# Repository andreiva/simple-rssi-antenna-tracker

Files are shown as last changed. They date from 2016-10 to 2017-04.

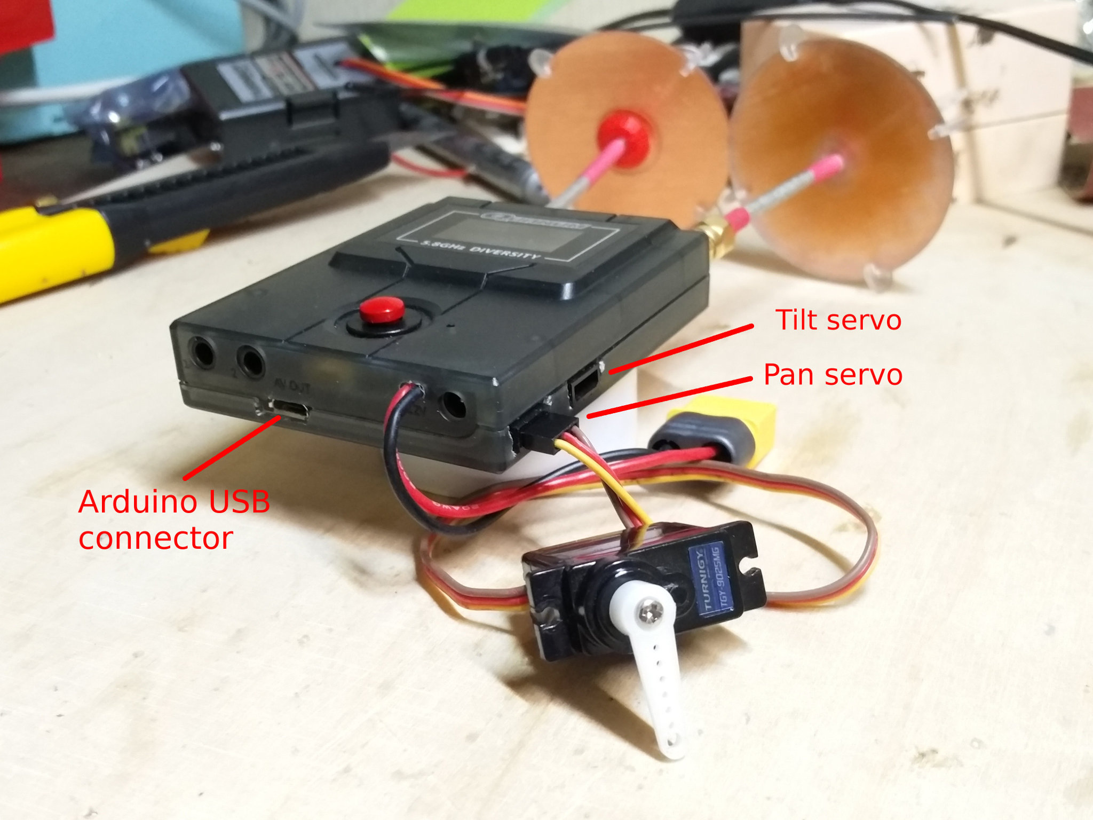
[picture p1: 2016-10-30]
images/assembled.jpg

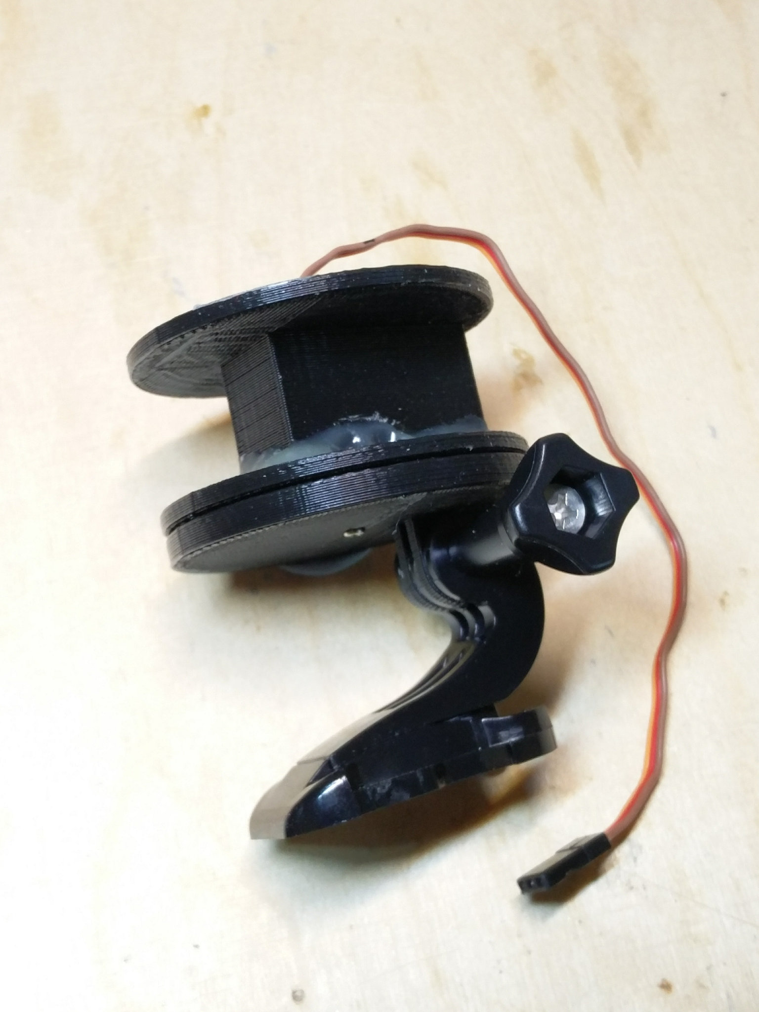
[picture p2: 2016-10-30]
images/servo-mount-2.jpg

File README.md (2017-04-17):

Simple RSSI Antenna Tracker
===========================

This tracker uses [Quanum RC540R 5.8GHz 40CH Race Band FPV Diversity Receiver](https://www.hobbyking.com/en_us/5-8ghz-32ch-8-race-channels-diversity-vrx.html)
which has two video receivers with RSSI output. RSSI is measured with an Arduino's analog inputs, signal strength is compared and tracker head is turned towards stronger signal with servo.

This tracker relies solely on RSSI, no GPS or compass is involved.
This means you can track any 5.8GHz signal source to which the receiver is tuned to.
No pairing, no telemetry, no configuration, just tune and track.

### Pros:
* It's cheap and simple. You probably already have most of the the parts.
* no GPS needed
* no telemetry needed
* can track any 5.8GHz source

### Cons:
* tracking is relative
* tracker doesn't really know where the target is
* may wander off target
* tracks only in horizontal axis

# What will you need
* [Quanum RC540R 5.8GHz 40CH Race Band FPV Diversity Receiver](https://www.hobbyking.com/en_us/5-8ghz-32ch-8-race-channels-diversity-vrx.html)
    * known to work with: FR632, Boscam D58-2
* Two directional 5.8GHz antennas, helical or patch
* [Arduino Pro Mini ATmega32U4](http://www.ebay.com/sch/i.html?_from=R40&_sacat=0&_nkw=Arduino++atmega+32u4&rt=nc&LH_BIN=1) $4
* One servo, 9 gramms or similar 4$
* [5V voltage regulator](http://www.ebay.com/sch/i.html?_from=R40&_trksid=p2047675.m570.l1313.TR0.TRC0.H0.TRS0&_nkw=MP1584EN&_sacat=0)
* tracker head mount, 3D printed or made from scrap

### Youtube video
[https://www.youtube.com/watch?v=aACTKziuDVE](https://www.youtube.com/watch?v=aACTKziuDVE)

### Timer.h Arduino library
To install Timer library, download the ZIP file here:
[https://github.com/JChristensen/Timer](https://github.com/JChristensen/Timer)

How to install libraries
[https://www.youtube.com/watch?v=Alz-rX6lkEw](https://www.youtube.com/watch?v=Alz-rX6lkEw)

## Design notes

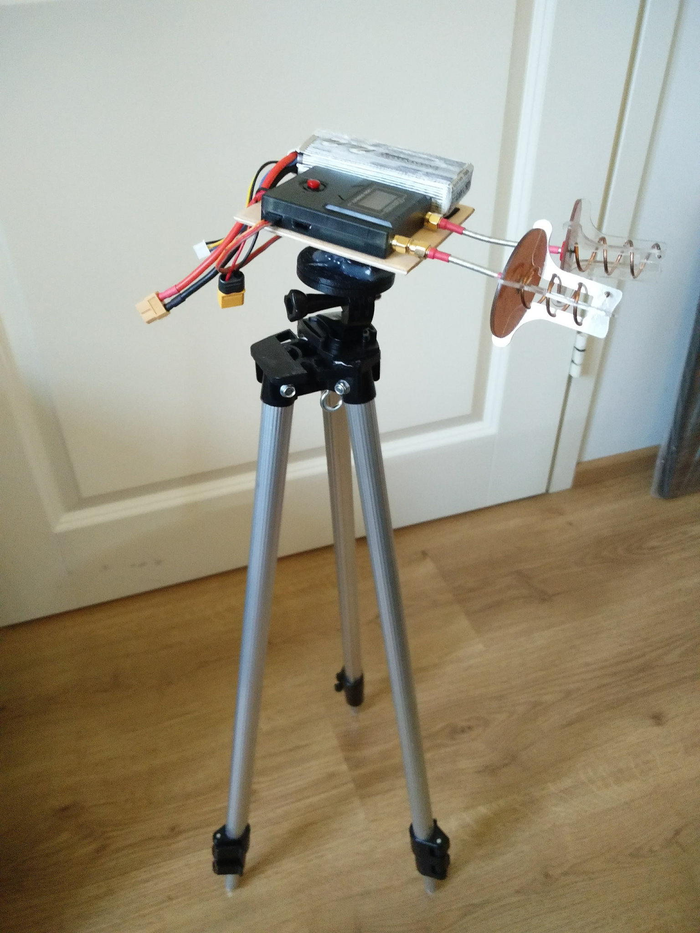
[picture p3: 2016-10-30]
images/tripod.jpg

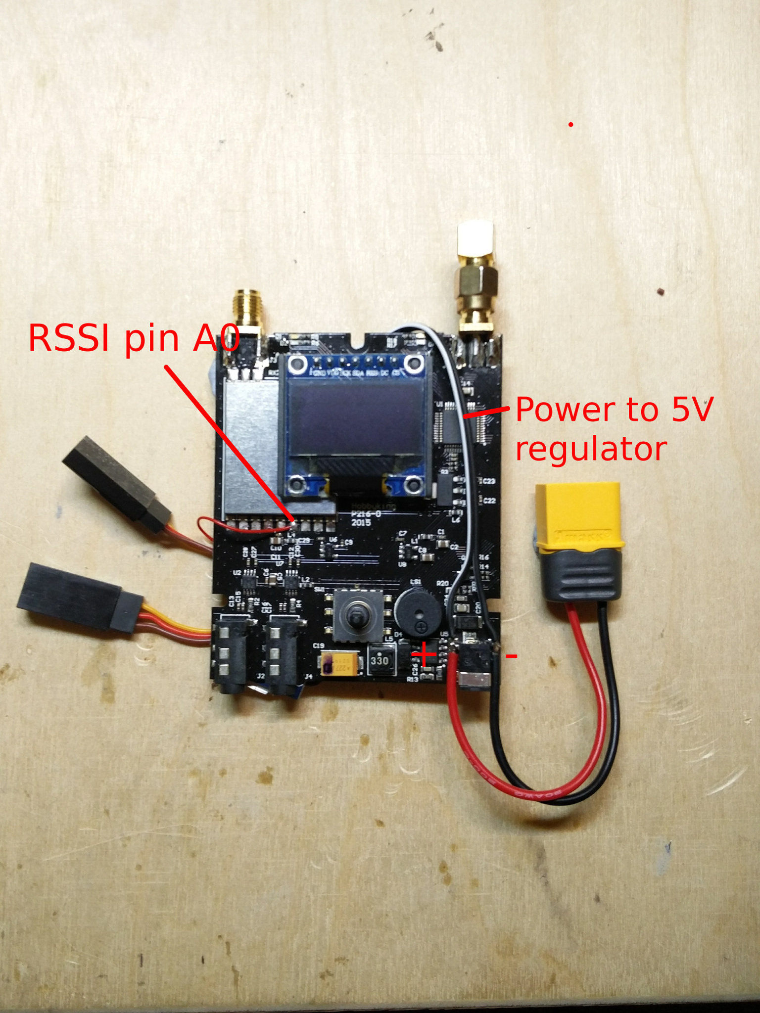
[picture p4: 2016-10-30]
images/top.jpg

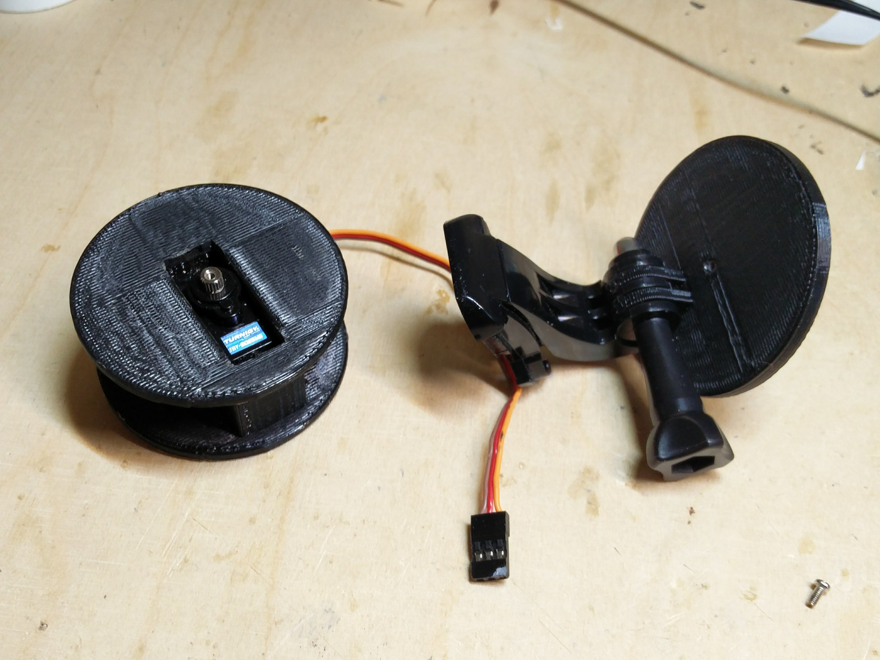
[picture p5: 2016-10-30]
images/servo-mount-1.jpg

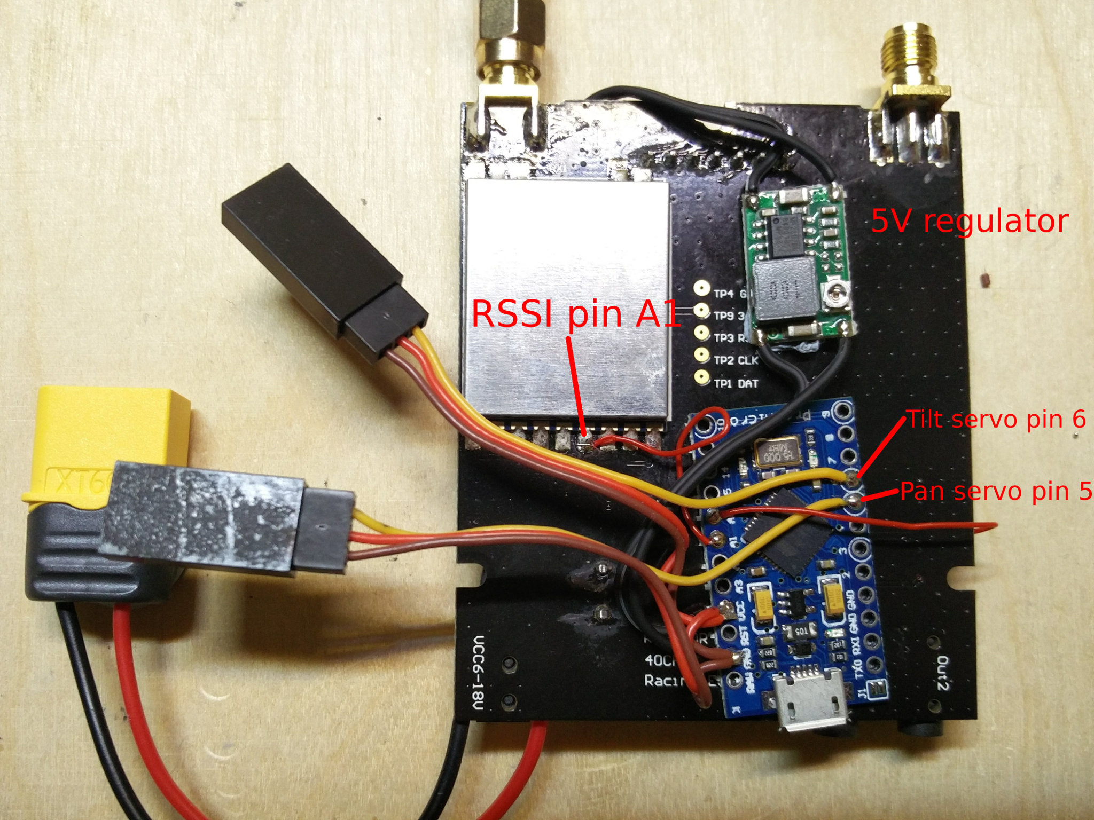
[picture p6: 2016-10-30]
images/bottom.jpg

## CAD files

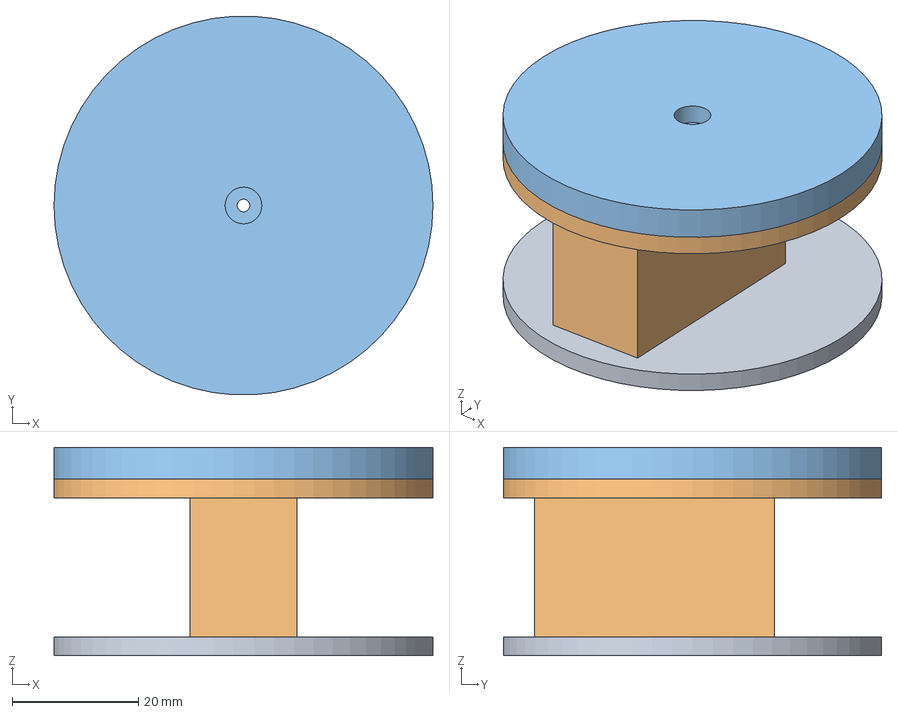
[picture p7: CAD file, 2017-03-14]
servo-mount-3d/tracke-servo-rig.fcstd
60.0 x 59.9 x 33.0 mm

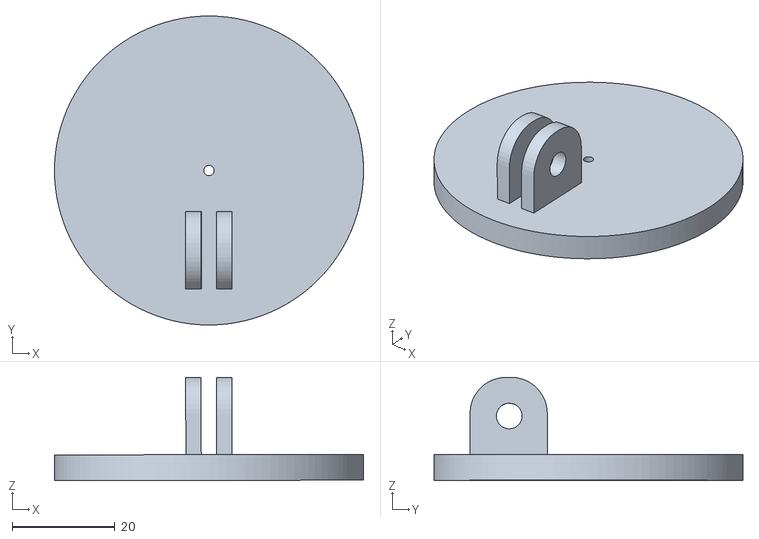
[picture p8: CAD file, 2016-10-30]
servo-mount-3d/bottom-gopro.stl
60.0 x 60.0 x 20.1

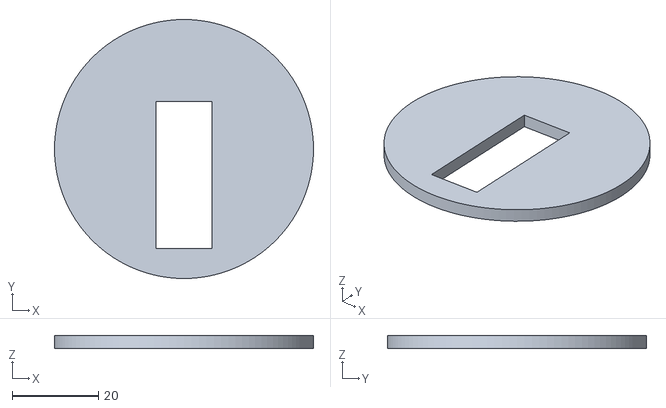
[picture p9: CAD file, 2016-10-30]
servo-mount-3d/servo-body-bottom.stl
60.0 x 60.0 x 3.00

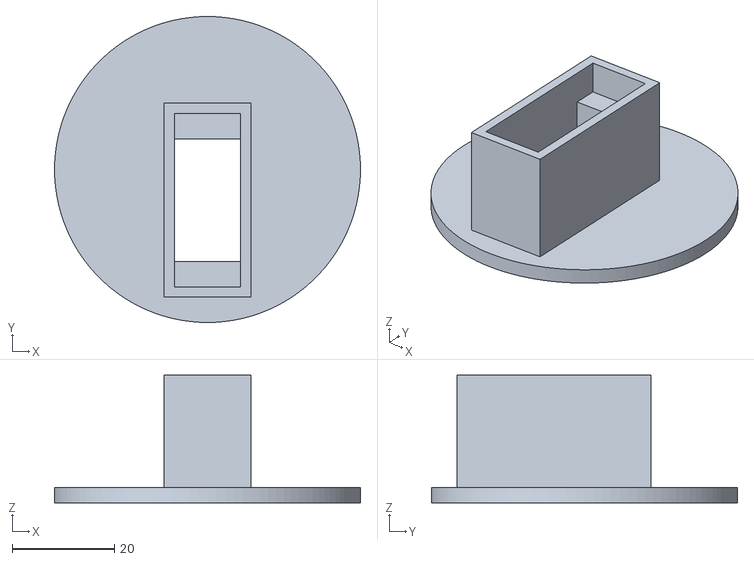
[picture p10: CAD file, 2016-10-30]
servo-mount-3d/servo-body.stl
60.0 x 60.0 x 25.0

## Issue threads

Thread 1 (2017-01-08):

error: 'Timer' does not name a type

MoistNugget666, 2017-01-08:
`simple-rssi-antenna-tracker.ino:101: error: 'Timer' does not name a type
simple-rssi-antenna-tracker.ino: In function 'void setup()':
simple-rssi-antenna-tracker.ino:122: error: 'timer' was not declared in this scope
simple-rssi-antenna-tracker.ino: In function 'void loop()':
simple-rssi-antenna-tracker.ino:129: error: 'timer' was not declared in this scope
`
hello,
im fairly new to adruino programming and get this when i try to compile. any idea how to fix it?

andreiva, 2017-01-09:
Hi,
the problem is missing Timer.h library, you need to install it manually.
Download ZIP file from here https://github.com/JChristensen/Timer  then
extract zip content in (assuming youre using windows) My
Documents\Arduino\libraries\

There are several ways to install libraries, check out this video:
https://www.youtube.com/watch?v=K1cIWCBKaUY

-Andrei

On Sun, Jan 8, 2017 at 4:47 PM, MoistNugget666 <notifications@github.com>
wrote:

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

yoowicked, 2018-12-06:
Need help here! I am using arduino1.0.5 and have installed the timer library but still having the same error message. Any advice to sort it out?

yoowicked, 2018-12-06:
By the way, the video link in your comment is no longer available. Do you have another link? Thanks!

andreiva, 2018-12-11:
Hi, just search YouTube "how to install libraries in adruino" or something
similar. There should plenty of results.

On Dec 6, 2018 08:59, "yoowicked" <notifications@github.com> wrote:

By the way, the video link in your comment is no longer available. Do you
have another link? Thanks!

—
You are receiving this because you commented.

Reply to this email directly, view it on GitHub
<https://github.com/andreiva/simple-rssi-antenna-tracker/issues/1#issuecomment-444768768>,
or mute the thread
<https://github.com/notifications/unsubscribe-auth/ABtNEHdngVj-orlfRdJBvW0o8JX9w2buks5u2MA0gaJpZM4LdtNV>
.

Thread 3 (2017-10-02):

Cant compile

FranzAr, 2017-10-02:
Tried to compile the sketch, but won't work. Any idea what may be the problem

Greets, Franz

```
Arduino: 1.8.5 (Windows 8.1), Board: "Arduino Nano, ATmega328P"

Build-Optionen wurden verändert, alles wird neu kompiliert
D:\arduino\tracker\simple-rssi-antenna-tracker\simple-rssi-antenna-tracker.ino: In function 'void setup()':

simple-rssi-antenna-tracker:122: error: no matching function for call to 'Timer::every(int, void (&)())'

   timer.every(50, mainLoop);

                           ^

D:\arduino\tracker\simple-rssi-antenna-tracker\simple-rssi-antenna-tracker.ino:122:27: note: candidates are:

In file included from D:\arduino\tracker\simple-rssi-antenna-tracker\simple-rssi-antenna-tracker.ino:10:0:

C:\Users\Franz\Documents\Arduino\libraries\Timer-2.1/Timer.h:40:10: note: int8_t Timer::every(long unsigned int, void (*)(void*), void*)

   int8_t every(unsigned long period, void (*callback)(void*), void* context);

          ^

C:\Users\Franz\Documents\Arduino\libraries\Timer-2.1/Timer.h:40:10: note:   candidate expects 3 arguments, 2 provided

C:\Users\Franz\Documents\Arduino\libraries\Timer-2.1/Timer.h:41:10: note: int8_t Timer::every(long unsigned int, void (*)(void*), int, void*)

   int8_t every(unsigned long period, void (*callback)(void*), int repeatCount, void* context);

          ^

C:\Users\Franz\Documents\Arduino\libraries\Timer-2.1/Timer.h:41:10: note:   candidate expects 4 arguments, 2 provided

simple-rssi-antenna-tracker:123: error: no matching function for call to 'Timer::every(int, void (&)())'

   timer.every(5, measureRSSI);

                             ^

D:\arduino\tracker\simple-rssi-antenna-tracker\simple-rssi-antenna-tracker.ino:123:29: note: candidates are:

In file included from D:\arduino\tracker\simple-rssi-antenna-tracker\simple-rssi-antenna-tracker.ino:10:0:

C:\Users\Franz\Documents\Arduino\libraries\Timer-2.1/Timer.h:40:10: note: int8_t Timer::every(long unsigned int, void (*)(void*), void*)

   int8_t every(unsigned long period, void (*callback)(void*), void* context);

          ^

C:\Users\Franz\Documents\Arduino\libraries\Timer-2.1/Timer.h:40:10: note:   candidate expects 3 arguments, 2 provided

C:\Users\Franz\Documents\Arduino\libraries\Timer-2.1/Timer.h:41:10: note: int8_t Timer::every(long unsigned int, void (*)(void*), int, void*)

   int8_t every(unsigned long period, void (*callback)(void*), int repeatCount, void* context);

          ^

C:\Users\Franz\Documents\Arduino\libraries\Timer-2.1/Timer.h:41:10: note:   candidate expects 4 arguments, 2 provided

exit status 1
no matching function for call to 'Timer::every(int, void (&)())'

```

andreiva, 2017-10-03:
Looks like you haven't installed Timer library. Take a look at README, there you'll find instructions how to do it.

FranzAr, 2017-10-03:
I'm sorry but timer is installed. Tried it on 2 different machines and several Arduino versions. Can't compile it, alway the same errors. Maybe I'm to stupid, sorry

FranzAr, 2017-10-03:
Found it, 2.x timer lib is not working, had to take old 1.3 branch. Now it works. Maybe you should mention this somewhere ;-) Thank you

andreiva, 2017-10-03:
Okay thanks, I'll check it out later.

Closed 2017-10-03.

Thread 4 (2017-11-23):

code issue

vannoz, 2017-11-23:
hello Andrei, I got an error when trying to compile this code...
[code]
`//#include <LiquidCrystal.h>

/*
  Simple RSSI Antenna Tracker
  RELATIVE
*/

#include <Servo.h>
#include <Timer.h>

/*
    For testing different curves
    All new curves are more precise
    and maintain lock better than old RELATIVE

    Uncomment one
*/
//#define EXPONENTIAL       // OK
//#define RELATIVE          // old, don't use
#define SIGMOID             // Best
//#define PROPORTIONAL      // twitchy

#define SIGMOID_SLOPE       1
#define SIGMOID_OFFSET      4

#if !defined(EXPONENTIAL) ^ !defined(SIGMOID) ^ !defined(PROPORTIONAL) ^ !defined(RELATIVE)
// all good
#else
#error "Please define ONE tracking curve: EXPONENTIAL, SIGMOID, PROPORTIONAL, RELATIVE"
#endif

/*
   Pin mapping
   You can change these pins, just make sure that
   RSSI pins are analog inputs
   and servo pin supports PWM
*/
#define LEFT_RSSI_PIN       A0     // analog RSSI measurement pin
#define RIGHT_RSSI_PIN     A1
#define PAN_SERVO_PIN    13     // Pan servo pin

/*
   There is going to be some difference in receivers,
   one is going to be less sensitive than the other.
   It will result in slight offset when tracker is centered on target

   Find value that evens out RSSI
*/
#define RSSI_OFFSET_RIGHT   0
#define RSSI_OFFSET_LEFT    0

/*
   MIN and MAX RSSI values corresponding to 0% and 100% from receiver
   See serial monitor
*/
#define RSSI_MAX            400
#define RSSI_MIN            120

/*
   Safety limits for servo

   Find values where servo doesn't buzz at full deflection
*/
#define SERVO_MAX           180
#define SERVO_MIN           0

/*
   Servo 'speed' limits
   MAX and MIN step in degrees
*/
#define SERVO_MAX_STEP      5
#define SERVO_MIN_STEP      0.09     // prevents windup and servo crawl

/*
   Center deadband value!
   Prevents tracker from oscillating when target is in the center
   When using SIGMOID or EXPONENTIAL you can set this almost to 0
*/
#define DEADBAND            5
//int DEADBAND = analogRead(A2)/200; // tolleranza tra dx e sx entro cui non muovere il servo
/*
   Depending which way around you put your servo
   you may have to change direction

   either 1 or -1
*/
#define SERVO_DIRECTION     1

#define FIR_SIZE            10
#define LAST                FIR_SIZE - 1

uint16_t rssi_left_array[FIR_SIZE];
uint16_t rssi_right_array[FIR_SIZE];

float anglePan = 90;
boolean debug = false;
//LiquidCrystal lcd(12,11,5,4,3,2);

Timer timer;
Servo servoPan;
//----------------------------------------------------------------------------------//

void setup() {
  servoPan.attach(PAN_SERVO_PIN);
  servoPan.write(90);

  // lcd.begin(16,2);
  // lcd.setCursor(0,0);
  // lcd.print("pos");
  // lcd.setCursor(7,0); // pos....deg.......
  // lcd.print("deg");   // rssisx....rssidx...
  // lcd.setCursor(0,1); //
  // lcd.print("rssisx");
  // lcd.setCursor(10,1);
  // lcd.print("rssidx");

  // wipe array
  for (int i = 0; i < FIR_SIZE; i++) {
    rssi_right_array[i] = 0;
    rssi_left_array[i] = 0;
  }

  Serial.begin(115200);
  while (!debug) {
    delay(3000);
    debug = true;
  }

  timer.every(50, mainLoop);
  timer.every(5, measureRSSI);

}
//---------------------------------------------------------------------------------//
void loop() {

  timer.update();

}

//-------------------------------------------------------------------------------------------------//
void mainLoop() {

  uint16_t avgLeft = max(avg(rssi_left_array, FIR_SIZE) + RSSI_OFFSET_LEFT, RSSI_MIN);
  uint16_t avgRight = max(avg(rssi_right_array, FIR_SIZE) + RSSI_OFFSET_RIGHT, RSSI_MIN);

  //  If avg RSSI is above 90%, don't move
  //  if ((avgRight + avgLeft) / 2 > 360) {
  //    return;
  //  }

  /*
     the lower total RSSI is, the lower deadband gets
     allows more precise tracking when target is far away
  */
  uint8_t dynamicDeadband = (float(avgRight + avgLeft) / 2 - RSSI_MIN) / (RSSI_MAX - RSSI_MIN) * DEADBAND;

  // if target is in the middle, don't move
  if (abs(avgRight - avgLeft) < dynamicDeadband ) {
    return;
  }

  float ang = 0;

  // move towards stronger signal
  if (avgRight > avgLeft) {

#if defined(EXPONENTIAL)
    float x = float(avgRight - avgLeft);
    x = x * x / 500;
    ang = x * SERVO_DIRECTION * -1;
#endif

#if defined(RELATIVE)
    ang = float(avgRight / avgLeft) * (SERVO_DIRECTION * -1);
#endif

#if defined(SIGMOID)
    float x = float(avgRight - avgLeft) / 10;
    x = SERVO_MAX_STEP / (1 + exp(-SIGMOID_SLOPE * x + SIGMOID_OFFSET));
    ang = x * SERVO_DIRECTION * -1;
#endif

#if defined(PROPORTIONAL)
    float x = float(avgRight - avgLeft) / 10;
    ang = x * SERVO_DIRECTION * -1;
#endif
  }
  else {

#if defined(EXPONENTIAL)
    float x = float(avgLeft - avgRight);
    x = x * x / 500;
    ang = x * SERVO_DIRECTION;
#endif

#if defined(RELATIVE)
    ang = float(avgLeft / avgRight) * SERVO_DIRECTION;
#endif

#if defined(SIGMOID)
    float x = float(avgLeft - avgRight) / 10;
    x = SERVO_MAX_STEP / (1 + exp(-SIGMOID_SLOPE * x + SIGMOID_OFFSET));
    ang = x * SERVO_DIRECTION;
#endif

#if defined(PROPORTIONAL)
    float x = float(avgLeft - avgRight) / 10;
    ang = x * SERVO_DIRECTION;
#endif
  }

  // upper and lower limit for angle step
  ang = (abs(ang) > SERVO_MAX_STEP ? SERVO_MAX_STEP * ang / abs(ang) : ang);
  ang = (abs(ang) < SERVO_MIN_STEP ? 0 : ang);

  // move servo by n degrees
  movePanBy(ang);

  if (debug) {
    //    Serial.print("RSSI%: ");
    //    Serial.print(map(avgLeft, RSSI_MIN, RSSI_MAX, 0, 100));
    //    Serial.print(", ");
    //    Serial.print(map(avgRight, RSSI_MIN, RSSI_MAX, 0, 100));

    // raw rssi values, use these for RSSI_MIN and RSSI_MAX
    Serial.print("Calibration - left: ");
    Serial.print(avgLeft);
    Serial.print(" right: ");
    Serial.print(avgRight);

    Serial.print(" servo-angle: ");
    Serial.println(anglePan);
  }
}

void movePanBy(float angle) {

  anglePan += angle;
  anglePan = limit(SERVO_MIN, SERVO_MAX, anglePan);
  servoPan.write(anglePan);
}

void measureRSSI() {

  advanceArray(rssi_left_array, FIR_SIZE);
  advanceArray(rssi_right_array, FIR_SIZE);

  rssi_left_array[LAST] = analogRead(LEFT_RSSI_PIN);
  rssi_right_array[LAST] = analogRead(RIGHT_RSSI_PIN);
}

uint16_t avg(uint16_t samples[], uint8_t n) {

  uint32_t summ = 0;
  for (uint8_t i = 0; i < n; i++) {
    summ += samples[i];
  }

  return uint16_t(summ / n);
}

void advanceArray(uint16_t *samples, uint8_t n) {

  for (uint8_t i = 0; i < n - 1; i++) {
    samples[i] = samples[i + 1];
  }
}

float limit(float lowerLimit, float upperLimit, float var) {

  return min(max(var, lowerLimit), upperLimit);
}
//lcd.setCursor(4, 0);
//lcd.print(anglePan);
//lcd.setCursor(8, 1);
//lcd.print(LEFT_RSSI_PIN);
//lcd.setCursor(13, 1);
//lcd.print(RIGHT_RSSI_PIN);
`

*******************************************************************************
**1. the error i got is here follwing. the timer library is installed correctly..:**

libraries\Timer\Event.cpp.o (symbol from plugin): In function `Event::Event()':

(.text+0x0): multiple definition of `Event::Event()'

sketch\Event.cpp.o (symbol from plugin):(.text+0x0): first defined here

libraries\Timer\Event.cpp.o (symbol from plugin): In function `Event::Event()':

(.text+0x0): multiple definition of `Event::Event()'

sketch\Event.cpp.o (symbol from plugin):(.text+0x0): first defined here

libraries\Timer\Event.cpp.o (symbol from plugin): In function `Event::Event()':

(.text+0x0): multiple definition of `Event::update(unsigned long)'

sketch\Event.cpp.o (symbol from plugin):(.text+0x0): first defined here

libraries\Timer\Event.cpp.o (symbol from plugin): In function `Event::Event()':

(.text+0x0): multiple definition of `Event::update()'

sketch\Event.cpp.o (symbol from plugin):(.text+0x0): first defined here

libraries\Timer\Timer.cpp.o (symbol from plugin): In function `Timer::Timer()':

(.text+0x0): multiple definition of `Timer::Timer()'

sketch\Timer.cpp.o (symbol from plugin):(.text+0x0): first defined here

libraries\Timer\Timer.cpp.o (symbol from plugin): In function `Timer::Timer()':

(.text+0x0): multiple definition of `Timer::Timer()'

sketch\Timer.cpp.o (symbol from plugin):(.text+0x0): first defined here

libraries\Timer\Timer.cpp.o (symbol from plugin): In function `Timer::Timer()':

(.text+0x0): multiple definition of `Timer::stop(signed char)'

sketch\Timer.cpp.o (symbol from plugin):(.text+0x0): first defined here

libraries\Timer\Timer.cpp.o (symbol from plugin): In function `Timer::Timer()':

(.text+0x0): multiple definition of `Timer::update(unsigned long)'

sketch\Timer.cpp.o (symbol from plugin):(.text+0x0): first defined here

libraries\Timer\Timer.cpp.o (symbol from plugin): In function `Timer::Timer()':

(.text+0x0): multiple definition of `Timer::update()'

sketch\Timer.cpp.o (symbol from plugin):(.text+0x0): first defined here

libraries\Timer\Timer.cpp.o (symbol from plugin): In function `Timer::Timer()':

(.text+0x0): multiple definition of `Timer::findFreeEventIndex()'

sketch\Timer.cpp.o (symbol from plugin):(.text+0x0): first defined here

libraries\Timer\Timer.cpp.o (symbol from plugin): In function `Timer::Timer()':

(.text+0x0): multiple definition of `Timer::every(unsigned long, void (*)(), int)'

sketch\Timer.cpp.o (symbol from plugin):(.text+0x0): first defined here

libraries\Timer\Timer.cpp.o (symbol from plugin): In function `Timer::Timer()':

(.text+0x0): multiple definition of `Timer::every(unsigned long, void (*)())'

sketch\Timer.cpp.o (symbol from plugin):(.text+0x0): first defined here

libraries\Timer\Timer.cpp.o (symbol from plugin): In function `Timer::Timer()':

(.text+0x0): multiple definition of `Timer::after(unsigned long, void (*)())'

sketch\Timer.cpp.o (symbol from plugin):(.text+0x0): first defined here

libraries\Timer\Timer.cpp.o (symbol from plugin): In function `Timer::Timer()':

(.text+0x0): multiple definition of `Timer::oscillate(unsigned char, unsigned long, unsigned char, int)'
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
andreiva, 2017-11-28:
Were you able to solve the problem?

vannoz, 2017-11-28:
Hello...i tried to merge two .ino code, one is your code and one the
diversity rx5808 ino code....but they are using a same name library...the
timer.h
So there are some problem...can You send me your mail? I'll send you what i
did for your help...
Thanks

Il 28/nov/2017 12:58, "andreiva" <notifications@github.com> ha scritto:

Were you able to solve the problem?

—
You are receiving this because you authored the thread.
Reply to this email directly, view it on GitHub
<https://github.com/andreiva/simple-rssi-antenna-tracker/issues/4#issuecomment-347501543>,
or mute the thread
<https://github.com/notifications/unsubscribe-auth/AbS__sbHPh499y2M1WsJwNuCqUj5xLR0ks5s6_VogaJpZM4QoqqV>
.

vannoz, 2017-11-28:
you program doesn't allow to choose the video channel, so I found this code
which is a diversity based on the RX5808:
https://github.com/sheaivey/rx5808-pro-diversity

so I tried to put them together but I find a conflict on two libraries that
have the same name (timer.h) .... and i do not have the skills to make it
one

in the attached file, I tried to make the merge ... I also entered the
commands for the TILT servo .... but putting it on arduino, the servo
trembles ... it goes back and forth as crazy..

 hardware part:
in practice the antenna will consist of 4 helical antennas: Right and Left
to control the PAN servo modified to have 360deg, Up and Down for the
TILT....
then to get the video signal i think to use a fifth helicoidal antenna
mounted on the center and connected to my ImmersionRC diversity
receiver...where the second antenna is a omnidirectional

I have also purchased a 6-wire slip ring, in practice are sliding contact
lifts, so the pan can rotate 360   to infinity without wavering the cables
..

thanks
ciao
Andrea

2017-11-28 13:04 GMT+01:00 andrea vanni <andrea.vanni1@gmail.com>:

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

Mattxjax45, 2018-09-23:
did this ever work?

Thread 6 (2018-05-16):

Servo slot too narrow

MrDabrudda, 2018-05-16:
Servo slot is too small and will not allow a 9g servo to fit without pinching the wiring.  I have modified the servo-body model by importing the file into FreeCAD then exporting to a STEP file and using Fusion 360 to expand the servo slot 1mm each side.
[servo-body.zip](https://github.com/andreiva/simple-rssi-antenna-tracker/files/2009451/servo-body.zip)

Closed 2018-07-04.

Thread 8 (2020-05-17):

360 servo support

danielolsman, 2020-05-17:
I'm trying to get this tracker software to work with a 360 degrees servo, no luck so far.
the servo only spins faster and faster.

can 360 servo support please be added if possible ?

andreiva, 2020-05-17:
Long story short, 360 is supported, but you need right servo
*"The GWS S125 1T 2BB Sail Winch Servo is a unique servo that has a wider
rotation range than typical hobby servos. It rotates one full turn (360°)
over the standard 1-2 ms servo pulse range output"*

There are two types of servos:
- continuous rotation servos (like this one
<https://hobbyking.com/en_us/towerpro-mg90d-mini-digital-servo-2-4kg-0-08sec-13g.html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>)
which have no limits, they just rotate in either direction at adjustable
speed and never stop
- extended range servos (GWS S125 1T 2BB
<https://www.pololu.com/product/522>) which is what you want. This servo
goes from 0° to 360° and stops

I'm guessing you are using a continuous rotation servo?

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

danielolsman, 2020-05-17:
I understand now, I have a SPT 5525 servo which indeed is a continuous rotation servo.

Thanks for the explanation

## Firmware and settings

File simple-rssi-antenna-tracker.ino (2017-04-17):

/*
  Simple RSSI Antenna Tracker



RELATIVE
*/

#include <Servo.h>
#include <Timer.h>

/* 
 *  For testing different curves
 *  All new curves are more precise
 *  and maintain lock better than old RELATIVE
 *  
 *  Uncomment one 
 */
//#define EXPONENTIAL       // OK
//#define RELATIVE          // old, don't use
#define SIGMOID             // Best
//#define PROPORTIONAL      // twitchy

#define SIGMOID_SLOPE       1
#define SIGMOID_OFFSET      4

#if !defined(EXPONENTIAL) ^ !defined(SIGMOID) ^ !defined(PROPORTIONAL) ^ !defined(RELATIVE)
// all good
#else
  #error "Please define ONE tracking curve: EXPONENTIAL, SIGMOID, PROPORTIONAL, RELATIVE"
#endif


/*
   Pin mapping
   You can change these pins, just make sure that
   RSSI pins are analog inputs
   and servo pin supports PWM
*/
#define LEFT_RSSI_PIN       0     // analog RSSI measurement pin
#define RIGHT_RSSI_PIN      1
#define PAN_SERVO_PIN       5     // Pan servo pin

/*
   There is going to be some difference in receivers,
   one is going to be less sensitive than the other.
   It will result in slight offset when tracker is centered on target

   Find value that evens out RSSI
 */
#define RSSI_OFFSET_RIGHT   0
#define RSSI_OFFSET_LEFT    0

/*
   MIN and MAX RSSI values corresponding to 0% and 100% from receiver
   See serial monitor
*/
#define RSSI_MAX            400
#define RSSI_MIN            120

/*
   Safety limits for servo

   Find values where servo doesn't buzz at full deflection
*/
#define SERVO_MAX           180
#define SERVO_MIN           0

/*
 * Servo 'speed' limits
 * MAX and MIN step in degrees
 */
#define SERVO_MAX_STEP      5
#define SERVO_MIN_STEP      0.09     // prevents windup and servo crawl

/*
   Center deadband value!
   Prevents tracker from oscillating when target is in the center
   When using SIGMOID or EXPONENTIAL you can set this almost to 0
*/
#define DEADBAND            5

/*
   Depending which way around you put your servo
   you may have to change direction

   either 1 or -1
*/
#define SERVO_DIRECTION     1

#define FIR_SIZE            10
#define LAST                FIR_SIZE - 1


uint16_t rssi_left_array[FIR_SIZE];
uint16_t rssi_right_array[FIR_SIZE];

float anglePan = 90;
boolean debug = false;

Timer timer;
Servo servoPan;


void setup() {
  servoPan.attach(PAN_SERVO_PIN);
  servoPan.write(90);

  // wipe array
  for (int i = 0; i < FIR_SIZE; i++) {
    rssi_right_array[i] = 0;
    rssi_left_array[i] = 0;
  }

  Serial.begin(115200);
  while (!debug) {
    delay(3000);
    debug = true;
  }


  timer.every(50, mainLoop);
  timer.every(5, measureRSSI);
}


void loop() {

  timer.update();

}


void mainLoop() {

  uint16_t avgLeft = max(avg(rssi_left_array, FIR_SIZE) + RSSI_OFFSET_LEFT, RSSI_MIN);
  uint16_t avgRight = max(avg(rssi_right_array, FIR_SIZE) + RSSI_OFFSET_RIGHT, RSSI_MIN);

//  If avg RSSI is above 90%, don't move
//  if ((avgRight + avgLeft) / 2 > 360) {
//    return;
//  }

  /*
     the lower total RSSI is, the lower deadband gets
     allows more precise tracking when target is far away
  */
  uint8_t dynamicDeadband = (float(avgRight + avgLeft) / 2 - RSSI_MIN) / (RSSI_MAX - RSSI_MIN) * DEADBAND;

  // if target is in the middle, don't move
  if (abs(avgRight - avgLeft) < dynamicDeadband ) {
    return;
  }

  float ang = 0;

  // move towards stronger signal
  if (avgRight > avgLeft) {
  
  #if defined(EXPONENTIAL)
    float x = float(avgRight - avgLeft);
    x = x * x / 500;
    ang = x * SERVO_DIRECTION * -1;
  #endif

  #if defined(RELATIVE)
    ang = float(avgRight / avgLeft) * (SERVO_DIRECTION * -1);
  #endif

  #if defined(SIGMOID)
    float x = float(avgRight - avgLeft) / 10;
    x = SERVO_MAX_STEP / (1+ exp(-SIGMOID_SLOPE * x + SIGMOID_OFFSET));
    ang = x * SERVO_DIRECTION * -1;
  #endif
    
  #if defined(PROPORTIONAL)
    float x = float(avgRight - avgLeft) / 10;
    ang = x * SERVO_DIRECTION * -1;  
  #endif
  }
  else {

  #if defined(EXPONENTIAL)
    float x = float(avgLeft - avgRight);
    x = x * x / 500;
    ang = x * SERVO_DIRECTION;
  #endif

  #if defined(RELATIVE)
    ang = float(avgLeft / avgRight) * SERVO_DIRECTION;
  #endif

  #if defined(SIGMOID)
    float x = float(avgLeft - avgRight) / 10;
    x = SERVO_MAX_STEP / (1+ exp(-SIGMOID_SLOPE * x + SIGMOID_OFFSET));
    ang = x * SERVO_DIRECTION;
  #endif
    
  #if defined(PROPORTIONAL)
    float x = float(avgLeft - avgRight) / 10;
    ang = x * SERVO_DIRECTION;  
  #endif
  }

  // upper and lower limit for angle step
  ang = (abs(ang) > SERVO_MAX_STEP ? SERVO_MAX_STEP * ang/abs(ang) : ang);
  ang = (abs(ang) < SERVO_MIN_STEP ? 0 : ang);

  // move servo by n degrees
  movePanBy(ang);


  if (debug) {
//    Serial.print("RSSI%: ");
//    Serial.print(map(avgLeft, RSSI_MIN, RSSI_MAX, 0, 100));
//    Serial.print(", ");
//    Serial.print(map(avgRight, RSSI_MIN, RSSI_MAX, 0, 100));

    // raw rssi values, use these for RSSI_MIN and RSSI_MAX
    Serial.print("Calibration - left: ");
    Serial.print(avgLeft);
    Serial.print(" right: ");
    Serial.print(avgRight);

    Serial.print(" servo-angle: ");
    Serial.println(anglePan);
  }
}

void movePanBy(float angle) {

  anglePan += angle;
  anglePan = limit(SERVO_MIN, SERVO_MAX, anglePan);
  servoPan.write(anglePan);
}

void measureRSSI() {

  advanceArray(rssi_left_array, FIR_SIZE);
  advanceArray(rssi_right_array, FIR_SIZE);

  rssi_left_array[LAST] = analogRead(LEFT_RSSI_PIN);
  rssi_right_array[LAST] = analogRead(RIGHT_RSSI_PIN);
}

uint16_t avg(uint16_t samples[], uint8_t n) {

  uint32_t summ = 0;
  for (uint8_t i = 0; i < n; i++) {
    summ += samples[i];
  }

  return uint16_t(summ / n);
}

void advanceArray(uint16_t *samples, uint8_t n) {

  for (uint8_t i = 0; i < n - 1; i++) {
    samples[i] = samples[i + 1];
  }
}


float limit(float lowerLimit, float upperLimit, float var) {

  return min(max(var, lowerLimit), upperLimit);
}

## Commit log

2016-10-30 Add servo mount STL files
    [bottom-gopro.stl, servo-body-bottom.stl, servo-body.stl]
2016-12-22 Add new servo speed curves. Big improvement in accuracy and speed. EXPONENTIAL - exponential relation between left-to-right difference and servo speed SIGMOID - almost like EXPONENTIAL, good accuracy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
2016-12-25 Ho-ho-ho! Fix SIGMOID curve. It's still the best one.
    [simple-rssi-antenna-tracker.ino]
2017-01-28 Add instruction how to install Timer.h
2017-03-14 Add FreeCad files
    [tracke-servo-rig.fcstd]
